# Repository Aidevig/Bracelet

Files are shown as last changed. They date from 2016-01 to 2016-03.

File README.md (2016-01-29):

# Bracelet

This is the code source Aidevig bracelet prototype. The bracelet is built with arduino modules. 
Basically, it is a simple button enabling the use to send alerts. There a bluetooth module that is a entry point for mobile devices.
An app is necessary on the device to create, send, get updates.

## Boc

This folders contains de 3D model of the Aidevig components.
There are : 
* boitier : the container of the electronic module
* couvercle : the lid closing the bracelet

## Program

This is the source code of the program running on the Arduino module. The program manages : 
* Bluetooth communication
* Notifications
* Button
* Vibration
* Pulse sensor

Check out the source code and feel free to contribute.

## Electronic design

We used [EAGLE](http://www.cadsoftusa.com/) to design the electronic part.

# License

* [Apache 2.0](http://www.apache.org/licenses/LICENSE-2.0)

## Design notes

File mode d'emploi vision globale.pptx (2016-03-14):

## Les bases

Voir sur : https://zestedesavoir.com/tutoriels/686/arduino-premiers-pas-en-informatique-embarquee/742_decouverte-de-larduino/3415_quelques-bases-elementaires/

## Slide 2

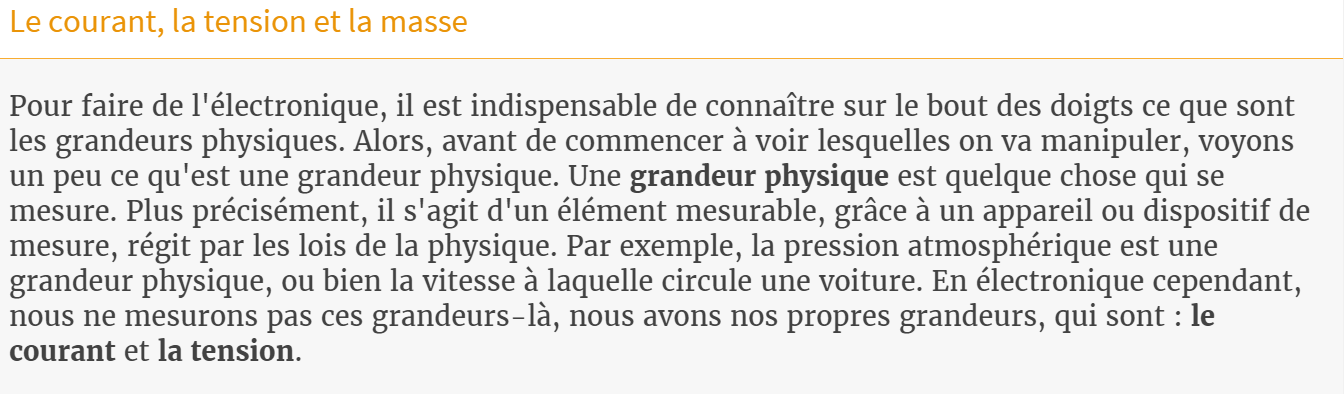
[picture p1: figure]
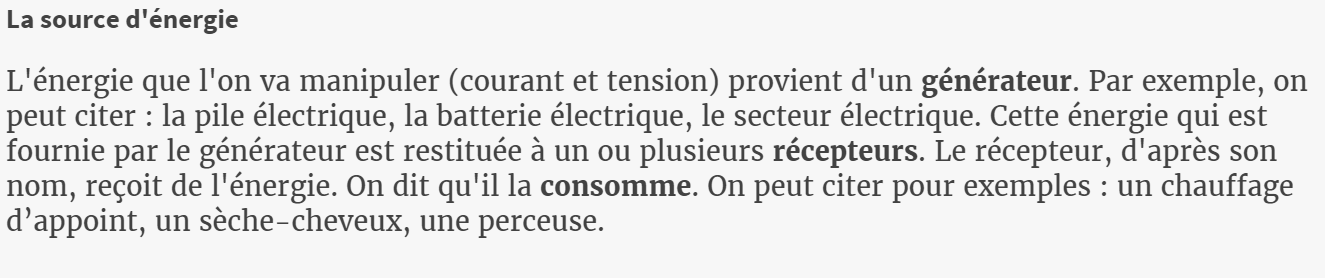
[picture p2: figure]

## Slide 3

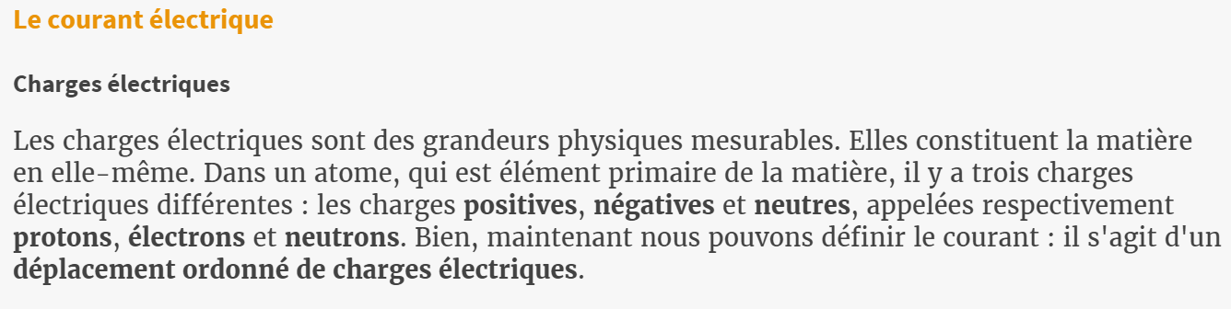
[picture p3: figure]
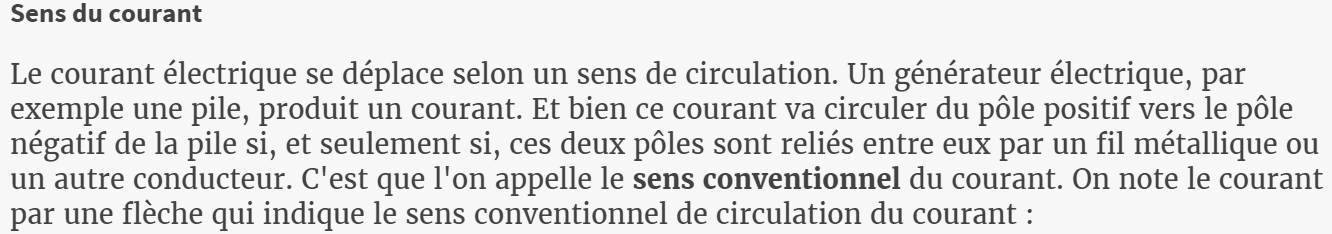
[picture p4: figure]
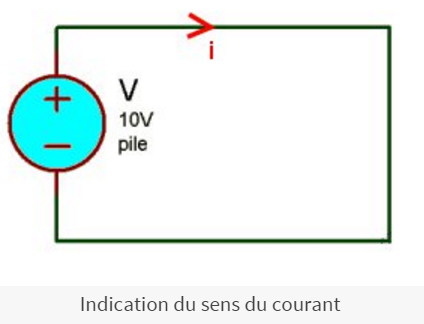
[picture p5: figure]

!

L’intensité du courant est la vitesse à laquelle circule ce courant. Tandis que le courant est un déplacement ordonné de charges électriques.

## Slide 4

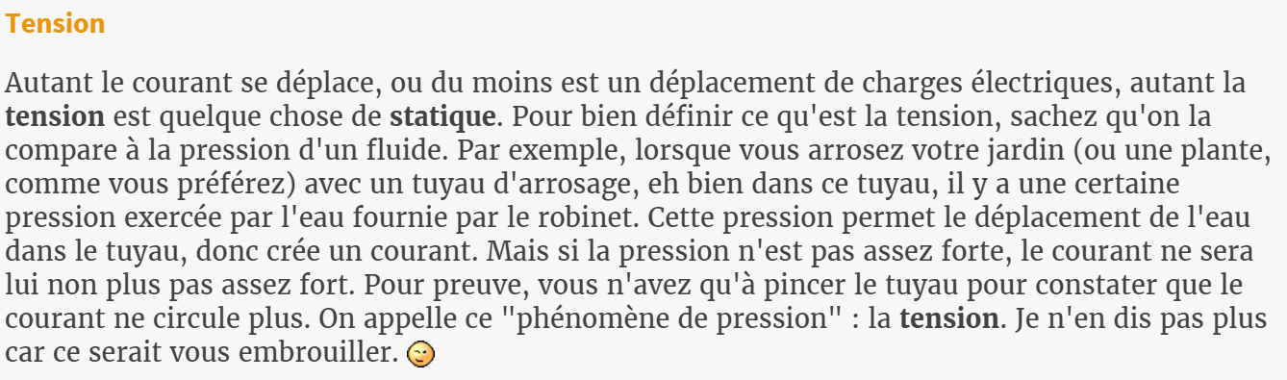
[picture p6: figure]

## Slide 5

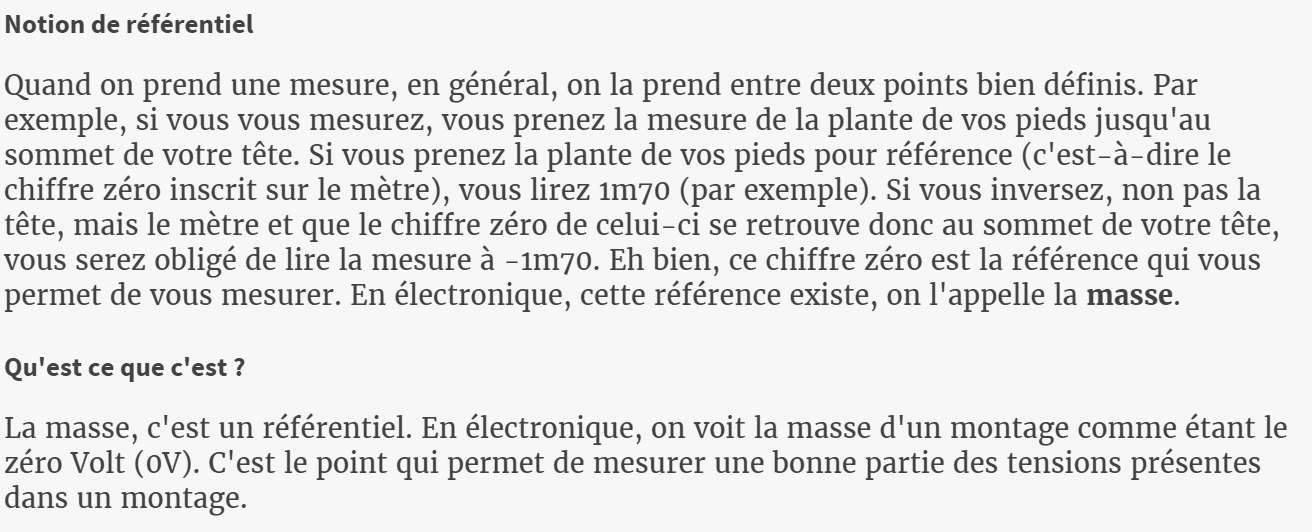
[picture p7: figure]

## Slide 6

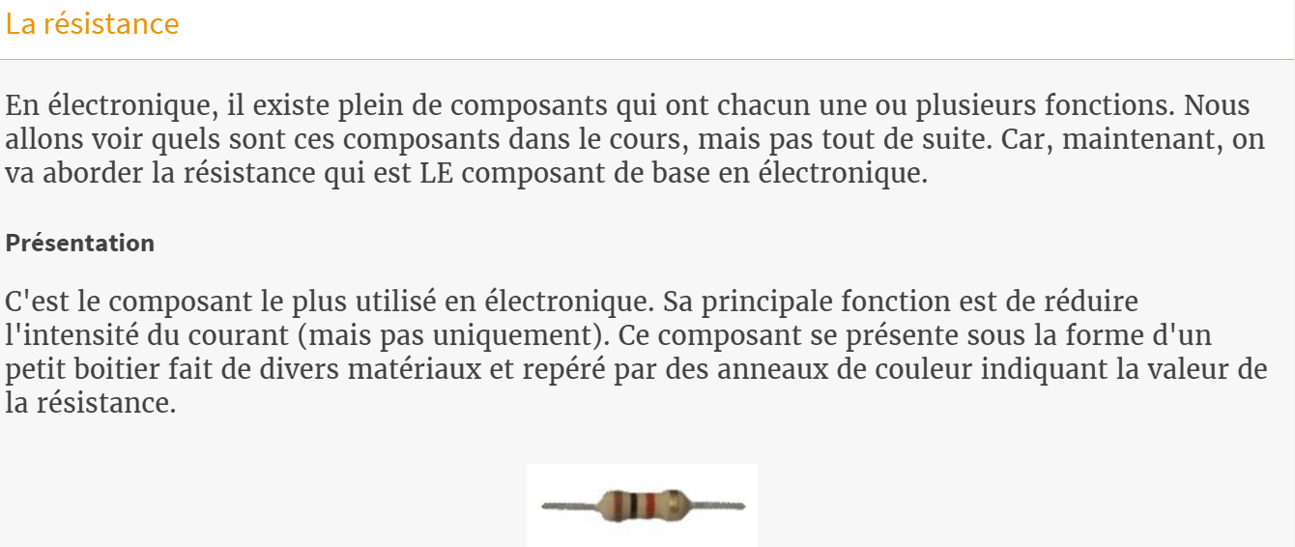
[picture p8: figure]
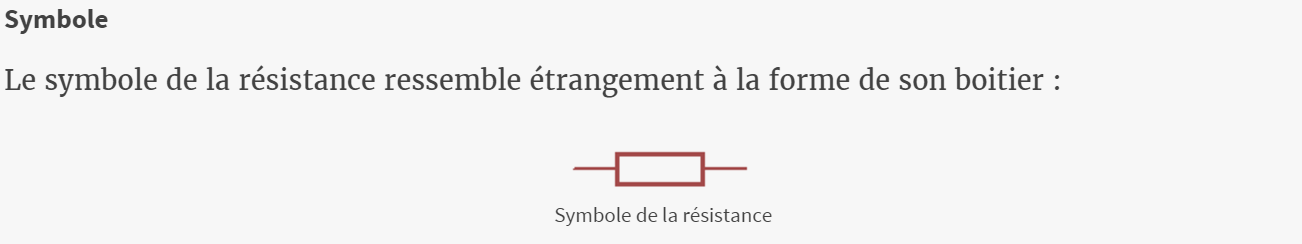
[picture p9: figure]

## De quoi est fait l’objet connecté ?

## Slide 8

Le quartz est une horloge. Il rythme toutes les actions du processeur. Le contrôleur possède déjà une horloge interne, mais nous ajoutons une pour être plus rapide.
On doit ajouter deux condensateurs de part à d’autre du quartz pour ajuster la fréquence. On peut faire des calculs complexes pour savoir la valeur des condensateurs, ou bien choisir des valeurs qui ont déjà été utilisées dans un montage et donc nous savons qu’elles marchent.

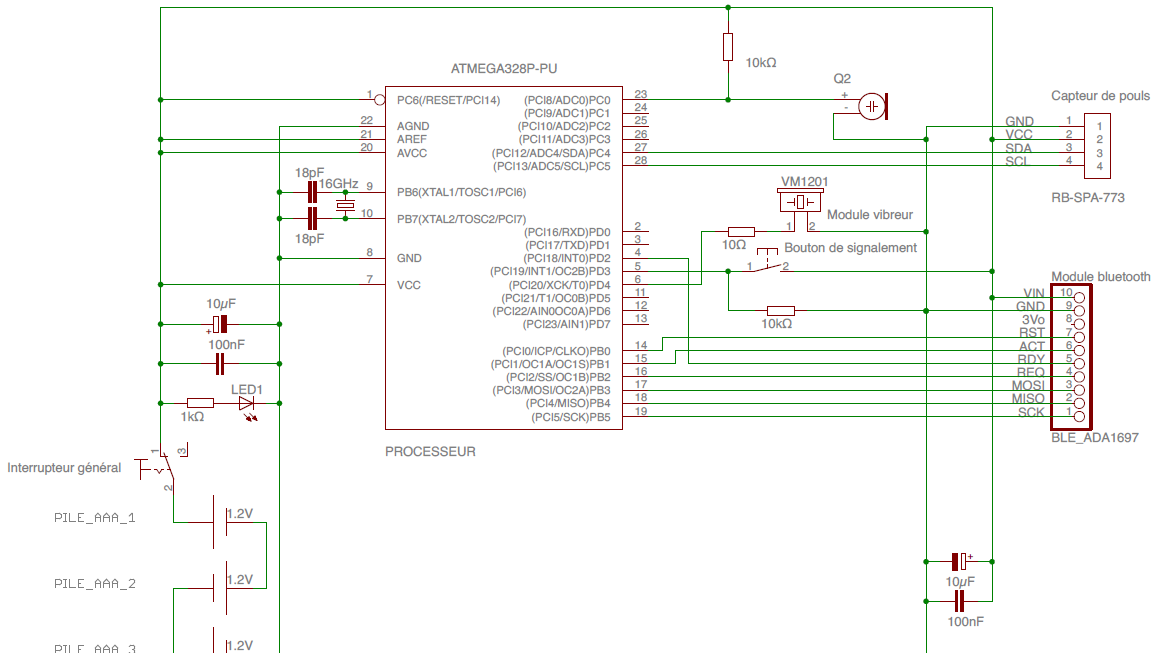
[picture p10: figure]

Le micro : il permet de détecter de fortes variations de voix, que l’on assimile à une situation anormale. C’est donc un des capteurs qui alimente notre objet intelligent. On l’accompagne d’une résistance de rappel : elle rappelle la tension pour stabiliser le niveau de tension à l’état bas (0V).
Le micro est polarisé : il faut faire attention au sens avant de le brancher.

Le capteur de pouls : c’est le deuxième capteur essentiel à notre objet intelligent. C’est grâce au rythme cardiaque que l’on peut détecter des pics de stress.
Lorsqu’on l’achète, il a déjà les 4 fils qui le relient à notre circuit.
Fil rouge : alimentation (VCC) et fil noir : la masse (GND).

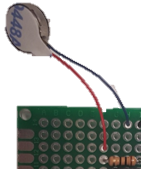
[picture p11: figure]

Module vibreur :
Il permet de transmettre à l’utilisateur une vibration, pour assurer que son alerte a bien été transmise.
On le relie à une résistance de 10Ω qui permet de diminuer l’intensité du courant qui traverse le vibreur.

La diode électroluminescente (LED) permet simplement d’indiquer si l’objet est allumé :
Lorsque l’interrupteur est sur ON, le courant passe et la diode s’allume.

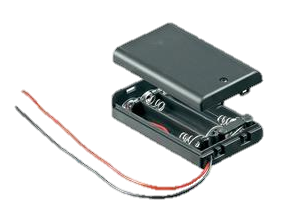
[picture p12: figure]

Pour alimenter notre objet en électricité, nous avons besoin d’une source de courant : les piles. 3 piles AAA de 1,2V chacune permettent d’avoir une tension entre 3,5 V et 5V. Il ne faut pas une tension supérieure à 5V.
Pensez à acheter des piles rechargeables
De petites piles (style pile de montres) ne conviennent pas car leur autonomie serait de moins d’1h.

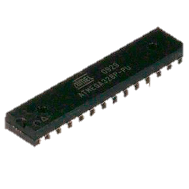
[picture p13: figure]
Afficher l'image d'origine

Le microcontrôleur est le cerveau de notre objet. C'est lui que nous allons programmer.

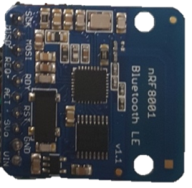
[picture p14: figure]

Module Bluetooth : C’est par lui que transitent toutes les données que l’objet envoie (pouls, forte intensité sonore, envoie d’une alerte) et qu’il reçoit (instruction d’émettre une vibration).
Nous avons choisi une connexion Bluetooth pour relier notre objet au téléphone pour pouvoir utiliser le GPS du téléphone. On pourrait se passer du module Bluetooth et avoir un objet indépendant du téléphone : on ajoute un GPS sur l’objet et on utilise un réseau comme LoRa ou Sigfox pour envoyer et recevoir les données. Dans ce cas, on devra payer un abonnement.

Bouton de signalement : permet d’envoyer manuellement un signal d’alerte en cas de danger. Lorsqu’on appuie sur le bouton, le circuit se ferme et le courant passe.
On l’accompagne d’une résistance de rappel : elle rappelle la tension pour stabiliser le niveau de tension à l’état bas (0V).

Tous les condensateurs de ce circuit (sauf ceux reliés à l’horloge) servent au filtrage antiparasite. Il existe des valeurs standards comme celles que l’on a choisies, et il faut prendre deux valeurs éloignées : une grande et une petite afin de filtrer un large panel de parasite.
Le condensateur avec de 10µF est polarisé : le courant ne passe pas de la même manière dans un sens et dans l’autre. On lui indique donc un +. Le côté + est relié à l’alimentation (VCC) et l’autre côté (côté -) est relié à la masse (GND = ground). Sur ces condensateurs, on repère le côté – car c’est celui où le condensateur comporte une bande blanche.

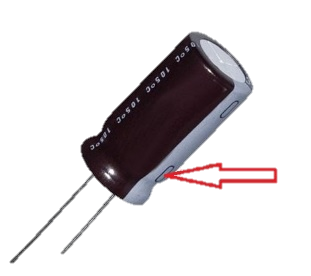
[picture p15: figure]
Afficher l'image d'origine

## Comment placer les composants ?

## To be continued…

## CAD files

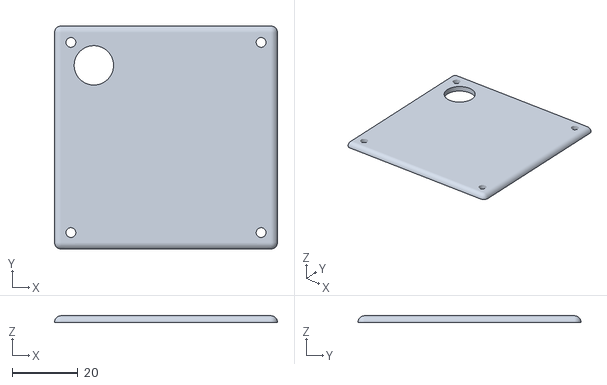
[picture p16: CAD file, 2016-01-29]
bracelet/boitier/couvercle go-safe.stl
68.0 x 68.0 x 2.00

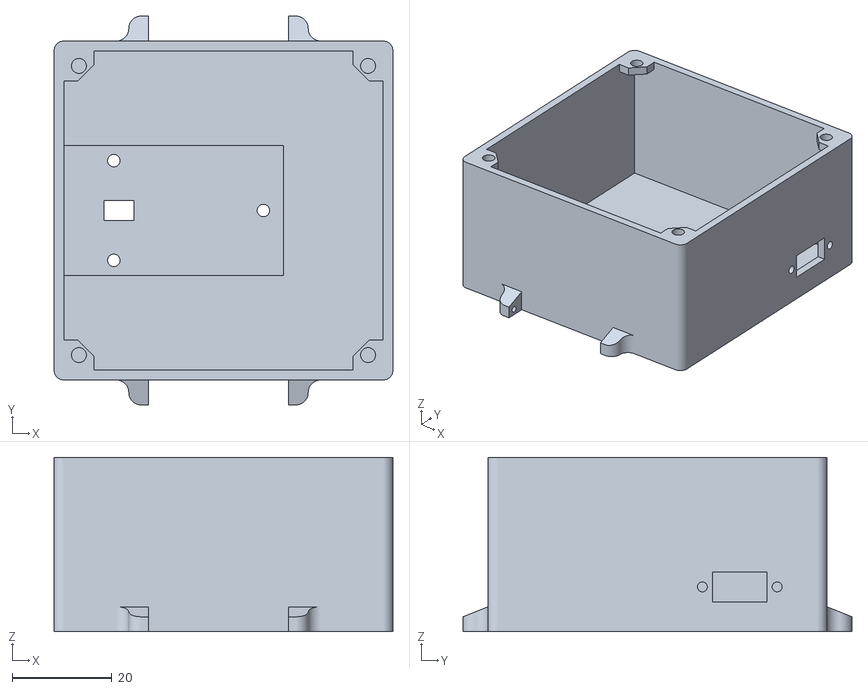
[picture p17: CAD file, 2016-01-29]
bracelet/boitier/boitier go-safe.stl
68.0 x 78.0 x 35.0

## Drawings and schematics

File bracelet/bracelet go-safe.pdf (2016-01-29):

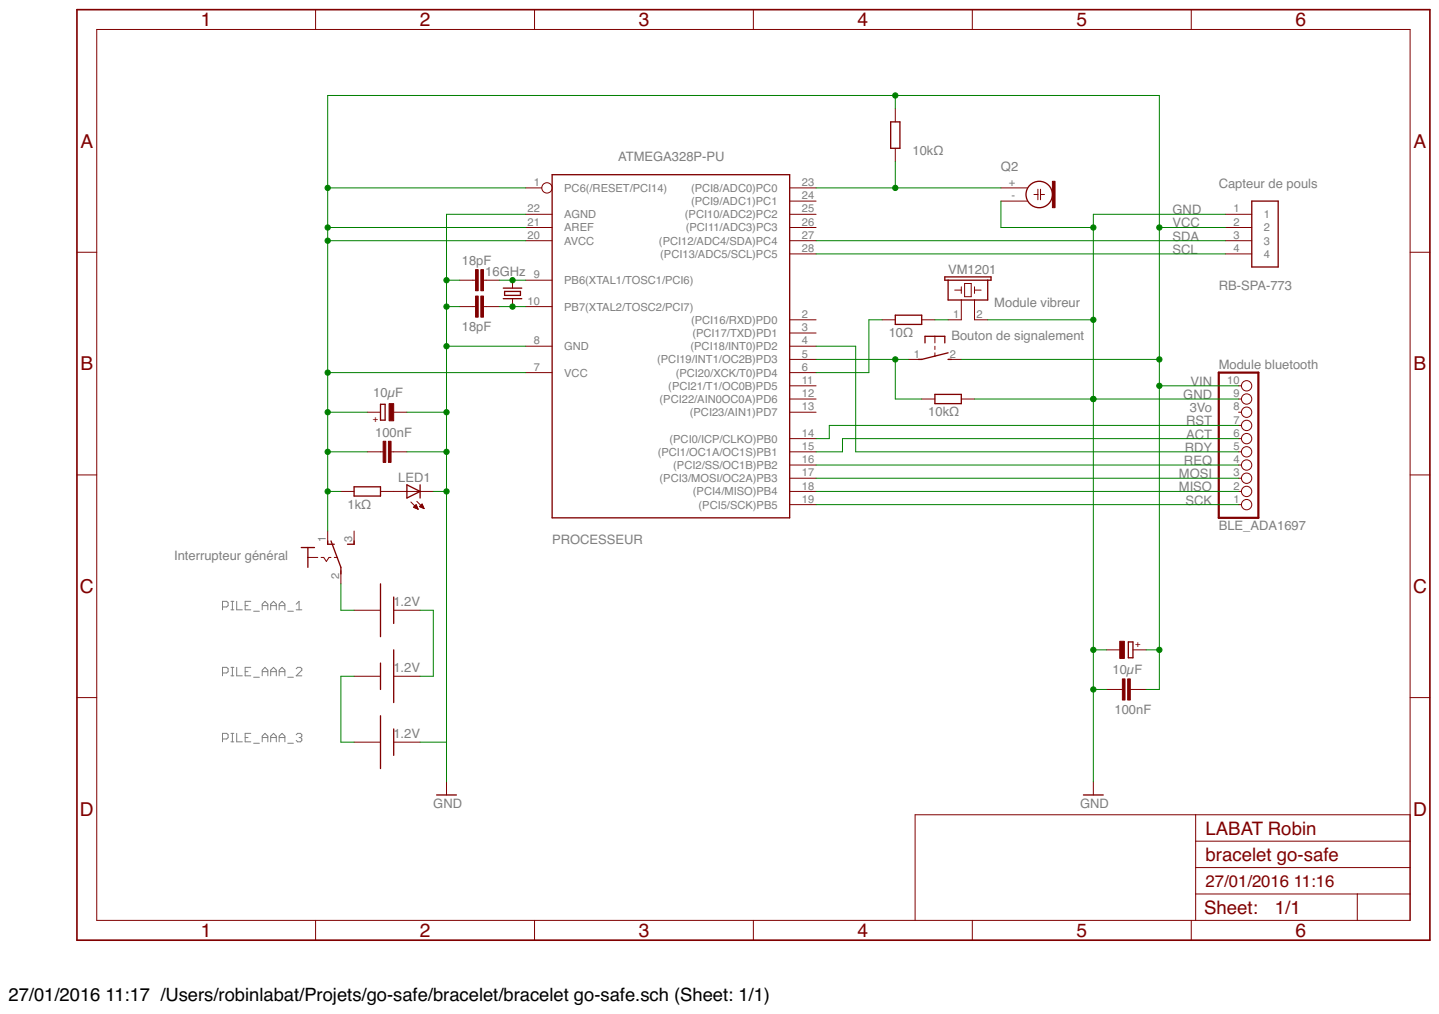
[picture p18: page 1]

Capteur de pouls SCL

27/01/2016 11:17 /Users/robinlabat/Projets/go-safe/bracelet/bracelet go-safe.sch (Sheet: 1/1)

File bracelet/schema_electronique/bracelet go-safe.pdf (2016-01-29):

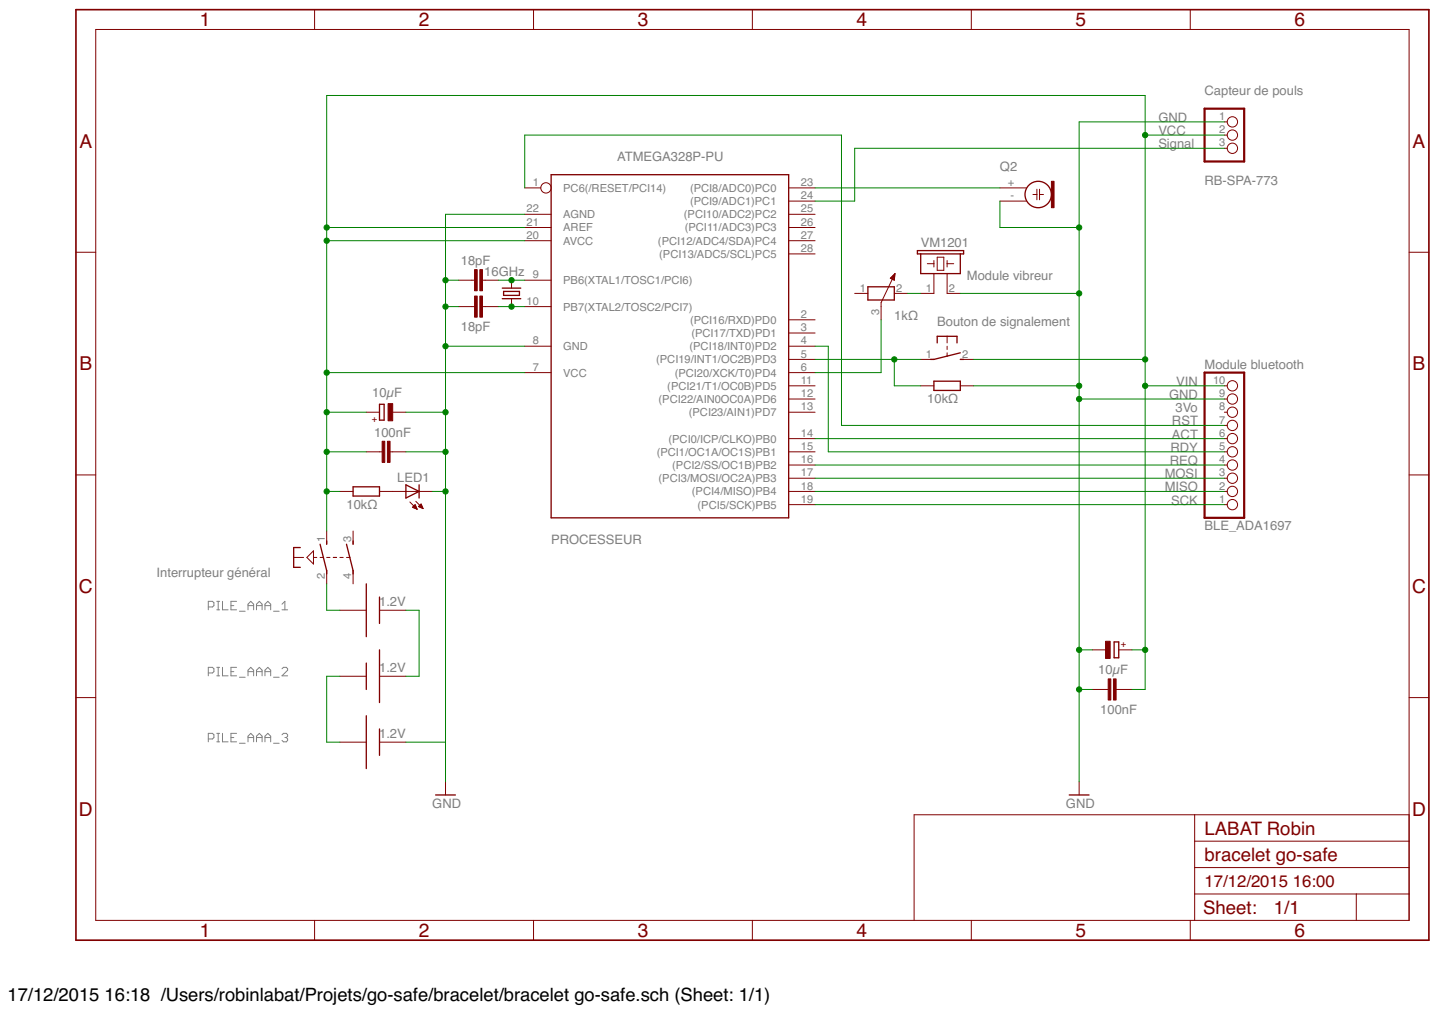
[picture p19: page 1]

17/12/2015 16:18 /Users/robinlabat/Projets/go-safe/bracelet/bracelet go-safe.sch (Sheet: 1/1)

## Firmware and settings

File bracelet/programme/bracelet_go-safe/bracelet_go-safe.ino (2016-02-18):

/**************************************************************************/
/*!
    Initialisation
*/
/**************************************************************************/

#include <SPI.h>
#include "Adafruit_BLE_UART.h"
#include <Wire.h>

#define ADAFRUITBLE_REQ 10
#define ADAFRUITBLE_RDY 3
#define ADAFRUITBLE_RST 8

Adafruit_BLE_UART uart = Adafruit_BLE_UART(ADAFRUITBLE_REQ, ADAFRUITBLE_RDY, ADAFRUITBLE_RST);

//  VARIABLES

int pulseStep = 120;              // Pulse frequency step that triggers an alert (BPM)
int pulseTime = 60;               // Time above pulseStep to trigger an alert (sec)
int pulseCount = 0;               // if this count is greater than the pulseTime an automatic alert is triggered
int notifTime = 60;               // Delay in which the device is waiting for the user to confirm an alert 
int timeout = 0;                  // Counter
int soundStep = 650;              // Sound step that triggers an alert
char notif = 'B';                 // Char sends when alert is triggered manually via the button
unsigned char heartRate = 0;      // HeartRate detected by the pulse sensor
boolean btnState = LOW;           // Initial state of the button
boolean btnValue;                 //

/**************************************************************************/
/*!
    This function is called whenever data arrives on the RX channel
    If the RX received begins by a 'V', the device vibrate for 1000ms
*/
/**************************************************************************/
void rxCallback(uint8_t *buffer, uint8_t len)
{
  if(buffer[0]=='V'){
    digitalWrite(6, HIGH);
    delay(1000);
    digitalWrite(6, LOW);
  }
}

/**************************************************************************/
/*!
    This function is called whenever the button is pressed
    Sends the char notif and the heart rate when the button is pressed
    Waits 10s before the next notification to avoid excessive signals
*/
/**************************************************************************/
void notify()
{
  uart.print(String(notif) + heartRate);   // Sends data through uart characteristic
  notif = 'B';                             // Resets the notif to the initial value
  delay(10000);                            // Waits 10 s before processing the next notification
}


/**************************************************************************/
/*!
    This function is called whenever an alert is triggered by the pulse or the sound sensor
    Two short vibrations notify the user of the detected alert
    The timeout is then the period of time during which the alert is in the pending state, 
    waiting for the user to confirm the alert
*/
/**************************************************************************/
void askForNotif(char c)
{
  digitalWrite(6, HIGH);
  delay(500);
  digitalWrite(6, LOW);
  delay(250);
  digitalWrite(6, HIGH);
  delay(500);
  digitalWrite(6, LOW);

  notif = c;
  timeout = notifTime * 2;
}

/**************************************************************************/
/*!
    This function sends an analog value and its type i.e askForNotif
    If the value i.e the heart rate is greater than the pulse step there are two cases
        Case 1 : the pulseCount is greater than 2, meaning we processed twice a dangerous heart rate, a notification is sent and the pulse count is reset to 0
        Otherwise, the pulseCount is incremented 
*/
/**************************************************************************/

void processData(int value)
{
  if(value >= pulseStep) {
    if(pulseCount >= pulseTime / 30) {
      if(timeout<=0){
        askForNotif('C');
        pulseCount =  0;
      }
    } else {
      pulseCount ++;
    }
  } else {
    pulseCount = 0;
  }
}
  
/**************************************************************************/
/*!
    Configure the Arduino and start advertising with the radio
*/
/**************************************************************************/
void setup(void)
{
  pinMode(6, OUTPUT);
  pinMode(2, INPUT);
  pinMode(A2, INPUT);
  Wire.begin();
  uart.setRXcallback(rxCallback);
  uart.setDeviceName("GO-SAFE"); /* 7 characters max! */
  uart.begin(); 
}

/**************************************************************************/
/*!
    Constantly checks for new events on the nRF8001
*/
/**************************************************************************/
void loop()
{
  uart.pollACI();

  Wire.requestFrom(0xA0 >> 1, 1);    // request 1 bytes from slave device 
  while(Wire.available()) {          // slave may send less than requested
    heartRate = Wire.read();         // receive heart rate value (a byte)
    processData(heartRate);          // process heartRate
  }

  for(int i = 0; i<25; i++){
    
    if (timeout<=0 && analogRead(A2) >= soundStep) {
      askForNotif('S'); 
    }

    btnValue = digitalRead(2);

    if(btnValue == HIGH && btnState == LOW){
      btnState = HIGH;
      notify();
    }
    if(btnValue == LOW){
      btnState = LOW;
    }

    delay(20);
  }

  if(timeout <= 0){
    notif = 'B';
  } else {
    timeout --; 
  }
}
